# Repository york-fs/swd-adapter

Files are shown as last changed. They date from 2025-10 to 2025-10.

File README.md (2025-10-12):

# SWD Programming Adapter

Enables a reliable connection between an **ST-Link clone** and a **1.27 mm 2×3 pin IDC connector**.  
Power output can be configured for **3.3 V** or **5 V** (default: **5 V**).  
Includes a **red status LED** to indicate power.

## Usage

- Connect the adapter to the ST-Link clone **with the board facing upward**.  
- Select the desired power level using the **solder bridge**:  
  - **5 V** is connected by default.  
  - To switch to **3.3 V**, **cut the 5 V bridge** and **solder the 3.3 V bridge** instead.  
- **Verify your ST-Link clone’s pinout** before making any connections.

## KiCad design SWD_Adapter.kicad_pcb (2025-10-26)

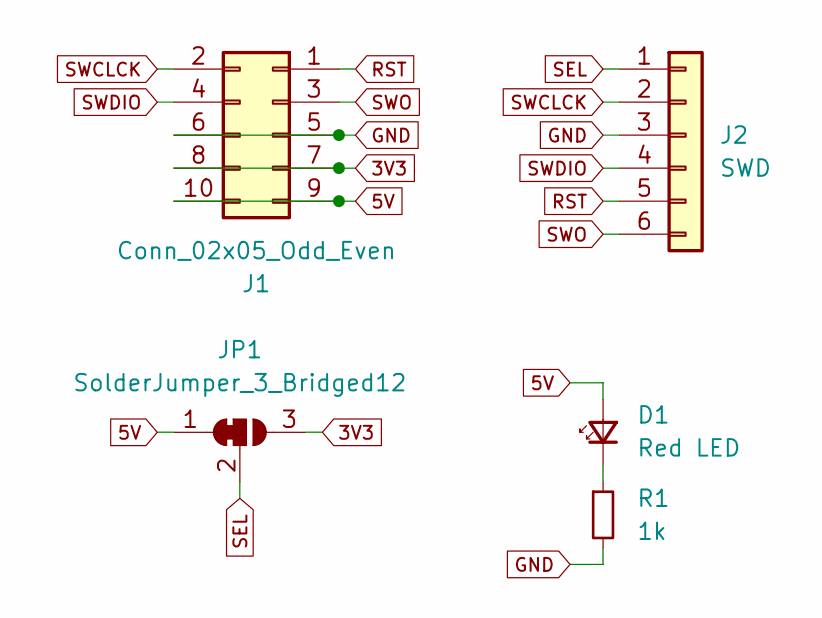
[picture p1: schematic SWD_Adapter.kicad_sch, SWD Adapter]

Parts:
D1: Red LED; LED_0603_1608Metric; Mfr # NCD0603R1
J1: Conn_02x05_Odd_Even; PinSocket_2x05_P2.54mm_Vertical; Mfr # ZX-PM2.54-2-5PWS
J2: SWD; IDC-Connector-2x3; Mfr # HX JN1.27-2x3P ZZ H4.9
JP1: SolderJumper_3_Bridged12; SolderJumper-3_P1.3mm_Bridged12_RoundedPad1.0x1.5mm
R1: 1k; R_0603_1608Metric; Mfr # 0603WAF1001T5E

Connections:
3V3: J1.7, J1.8, JP1.3 (B)
5V: D1.2 (A), J1.9, J1.10, JP1.1 (A)
GND: J1.5, J1.6, J2.3, R1.2
unnamed: D1.1 (K), R1.1
RST: J1.1, J2.5
SEL: J2.1, JP1.2 (C)
SWCLCK: J1.2, J2.2
SWDIO: J1.4, J2.4
SWO: J1.3, J2.6

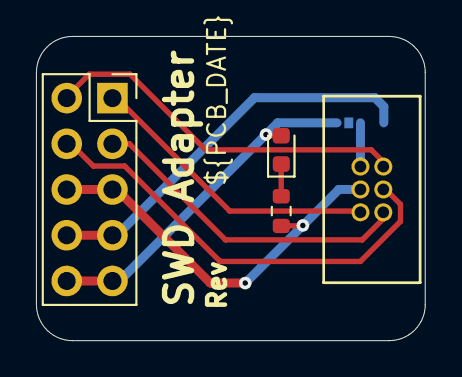
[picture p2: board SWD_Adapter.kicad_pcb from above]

Board: 2 copper layers, 21.6 x 16.9 mm, 5 parts (1 on the bottom side), 9 nets.

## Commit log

2025-10-26 kicad-library: Update to latest version
2025-10-26 project: Link to footprint library
2025-10-26 schematic: Fix DRC warning
    [SWD_Adapter.kicad_sch]
2025-10-26 bom: Fill in BOM info
    [SWD_Adapter.kicad_pcb, SWD_Adapter.kicad_sch]
